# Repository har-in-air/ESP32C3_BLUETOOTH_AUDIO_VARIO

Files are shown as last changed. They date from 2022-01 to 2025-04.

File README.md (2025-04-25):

# ESP32C3_BLUETOOTH_AUDIO_VARIO

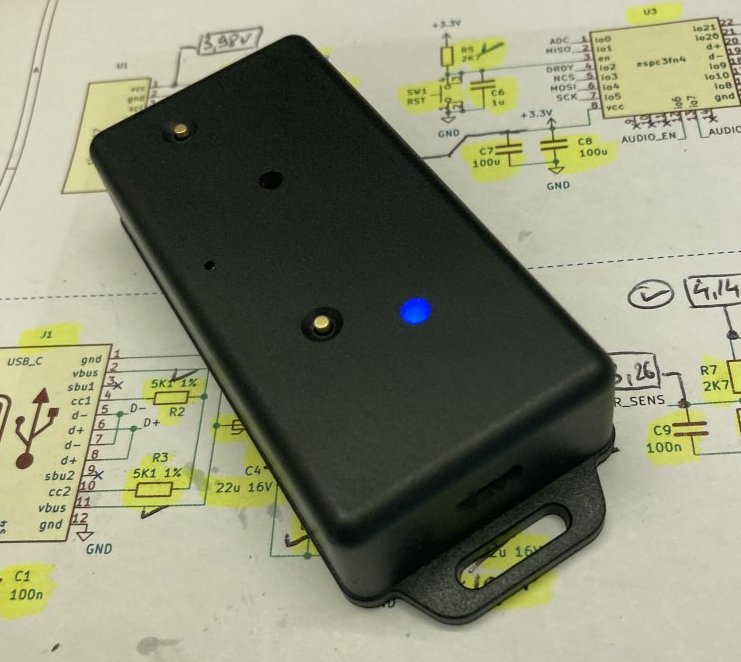
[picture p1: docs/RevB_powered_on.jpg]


 * Accurate, zero-lag audio variometer using Kalman filter fusion of accelerometer and pressure sensor data. 
 This project uses the [KF4D kalman filter algorithm](https://github.com/har-in-air/ESP32_IMU_BARO_GPS_VARIO/blob/master/offline/kf/compare_kf2_kf3_kf4.ipynb).

* WiFi Vario configuration via web page.
* Bluetooth LE transmission of [$LK8EX1 sentences](https://github.com/LK8000/LK8000/blob/master/Docs/LK8EX1.txt), to provide apps like [XCTrack](https://xctrack.org/) with 
accurate barometric pressure altitude and climb-rate data.
* Soft-switched power on/off.
* 'No activity' time-out power down  to conserve battery life.
* WiFi Over-the-air (OTA) firmware updates.
* [2-layer PCB layout available, sized for standard Hammond 1551K enclosure](https://github.com/har-in-air/VhARIO-ESPC3).

# Software Build Environment 
* Ubuntu 24.04 LTS AMDx64
* [Visual Studio Code with PlatformIO plugin using Arduino framework](https://randomnerdtutorials.com/vs-code-platformio-ide-esp32-esp8266-arduino/) 
* The file `platformio.ini` specifies the framework packages, toolchain and libraries used by the project. 
* LittleFS partition for hosting HTML web page content.
* Since release v1.20, the software only supports PCB layout revision B.

# Hardware

* AI-Thinker ESP-C3-12F C3FN4 module (4MByte flash, Wi-Fi and Bluetooth LE)
* CJMCU-117 module with MPU9250 9-DOF IMU and MS5611 barometric pressure sensor
* TLV75533 LDO regulator, max current 500mA
* KPEG006 broadband-audio piezo transducer
* 74HC240 used as a push-pull piezo driver for louder volume 
* MCP73871 Li-poly battery charger, max 500mA charging current
* 1800mAHr Lipoly battery
* The USB C interface supports Li-Poly battery charging and program flash/debug.

## Current Drain

With Bluetooth LE disabled, current drain is ~30mA.

With Bluetooth LE enabled and transmitting LK8EX1 messages at 10Hz, current drain is ~85mA.

# Software Build Notes

## Build Steps

* The first time you flash the ESP32-C3 with this project code, select `PROJECT TASKS -> esp32c3 -> Platform -> Erase Flash`. This will wipe the entire flash including any previous partition tables. 
* Next, select `Platform -> Build Filesystem Image`. This will build a LittleFS flash partition with the contents of the `/data` directory. The `/data` directory contains the static HTML and CSS files for the WiFi server webpage.
* Ensure the vario is switched off. 
* Connect the USB cable from your PC to the vario. 
* Press and hold the `PCCA (SW4)` button. 
* Close the jumper or slide-switch (`JP1/SW2)` depending on which part you have installed. 
* Release the `PCCA (SW4)` button. 
* You will see the USB serial/jtag port show up as a new serial port. On Ubuntu it will be `/dev/ttyACMx` instead of `/dev/ttyUSBx`. Set this new port as the upload and monitor port in platformio.ini.
* Next, select `Platform -> Upload Filesystem Image`. This will flash the LittleFS data partition to the ESP32-C3.
* Next, select `General -> Clean All`, then `Build`. This is only required once, to download the source code for the dependent libraries and build them. 
* If the libraries have already been downloaded and compiled, select `General -> Clean` to re-build only the project application code.
* Select `Build` to compile the application firmware binary. 
* Open the jumper/slide switch (`JP1/SW2`) to remove power. 
* Repeat the earlier steps with `PCCA (SW4)` and the jumper/slide switch  (`JP1/SW2`) to set up for flashing the application firmware.
* Select `Upload` to flash the application firmware binary.
* To see  serial debug prints and prompts on boot, open the  jumper/slide switch (`JP1/SW2`) to remove power. 
* Select `Monitor` in Visual Studio Code and then switch on the vario using the `PWR (SW3)` button. Note that the
serial port may change from the one used for upload e.g. from `ttyACM0` to `ttyACM1`.  

* After a full chip erase and firmware upload, there is no calibration data. So you will see a calibration error message. Follow the prompts to calibrate both accelerometer and gyroscope. Once complete, the calibration parameters will be saved to flash.
* [Example startup serial monitor output example after a full flash erase and build.](docs/first_boot_log.txt) 
* Example serial terminal output for normal vario boot (post-caliibration) : 

```
ESP-ROM:esp32c3-api1-20210207
Build:Feb  7 2021
ESP-ROM:esp32c3-api1-20210207
Build:Feb  7 2021
rst:0x15 (USB_UART_CHIP_RESET),boot:0xc (SPI_FAST_FLASH_BOOT)
Saved PC:0x42083766
SPIWP:0xee
mode:DIO, clock div:2
load:0x3fcd5810,len:0x438
load:0x403cc710,len:0x90c
load:0x403ce710,len:0x2624
entry 0x403cc710
E (236) esp_core_dump_flash: No core dump partition found!
E (236) esp_core_dump_flash: No core dump partition found!

ESP32-C3 BLUETOOTH VARIO compiled on Apr  8 2025 at 15:48:49
Firmware Revision 1.01

Load non-volatile configuration and calibration data from flash
WiFi AP credentials
SSID = 
VARIO
climbThresholdCps = 50
zeroThresholdCps = 5
sinkThresholdCps = -250
crossoverCps = 400
KALMAN FILTER
accelVariance = 100
adapt = 100
MISCELLANEOUS
pwrOffTimeoutMinutes = 10
bleEnable = true
Calibration Values
axBias = -390
ayBias = -182
azBias = 234
gxBias = 17
gyBias = -7
gzBias = 22
To start web configuration mode, press and hold the PCC button
until you hear a low-frequency tone. Then release the button
8
7
6
5
4
3
CPU Freq = 80 MHz
XTAL Freq = 40 MHz
APB Freq = 80000000 Hz
Vario mode

Audio indication of battery voltage

Battery voltage = 4.13V
E (4666) ledc: ledc_get_duty(745): LEDC is not initialized

Check communication with MS5611
crcPROM = 0x9, crc calculated = 0x9
MS5611 OK

Check communication with MPU9250
MPU9250 ID = 71, expected 0x71
MPU9250 OK
Counting down to gyro calibration
Press the PCCA button to enforce accelerometer calibration first
10
9
8
7
6
5
4
3
2
1

Calibrating gyro
Num Tries = 1
gxBias = 18
gyBias = -7
gzBias = 22
Gyro calibration OK

MS5611 config
MS5611 Calibration Coeffs : 48939 50595 29263 26380 30963 26826
Tavg : 35C
Pavg : 90986Pa
Zavg : 89864cm

KalmanFilter config
climbToneCps = 50
zeroesToneCps = 5
sinkToneCps = -250
crossoverCps = 400

Bluetooth LE LK8EX1 messages @ 10Hz

```
* The gyroscope is re-calibrated each time on power-up. You should leave the vario un-disturbed (in any orientation) when you hear the count-down beeps for gyroscope calibration. If the vario is disturbed during the gyro calibration process (e.g. you switched the vario on during flight), it will use the last saved gyro calibration parameters.

# WiFi Configuration

To put the vario into WiFi AP server mode, switch on the vario and immediately press and hold the `PCCA (SW4)` button. When you hear a confirmation tone, release the button. 

Connect to the WiFi Access Point `Vario-AP`, no password needed. 

Open the url `http://192.168.4.1` in a browser.
You can use `http://vario.local` with any OS that has mDNS support. MacOS has built-in support. For Ubuntu, install Avahi. For Windows, install Bonjour.

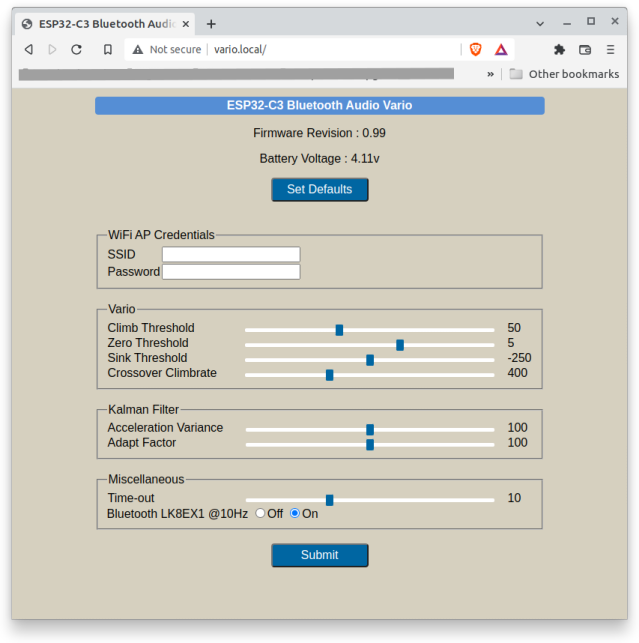
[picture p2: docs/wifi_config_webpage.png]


## Configuration Options

### WiFi Credentials
Enter your home WiFi Access Point SSID and password so that the vario can connect to the access point as a station. Then you can just enter the webpage url `http://vario.local` to access the vario configuration web page.

If the external Access Point is not configured or the configured access point is not available, e.g. on the launch site, the vario will configure itself as a standalone Wifi Access Point with SSID `Vario-AP`, no password. You can use your phone or tablet to connect first to this access point. Then access the webpage url `http://vario.local` as before.

### Audio Tone configuration

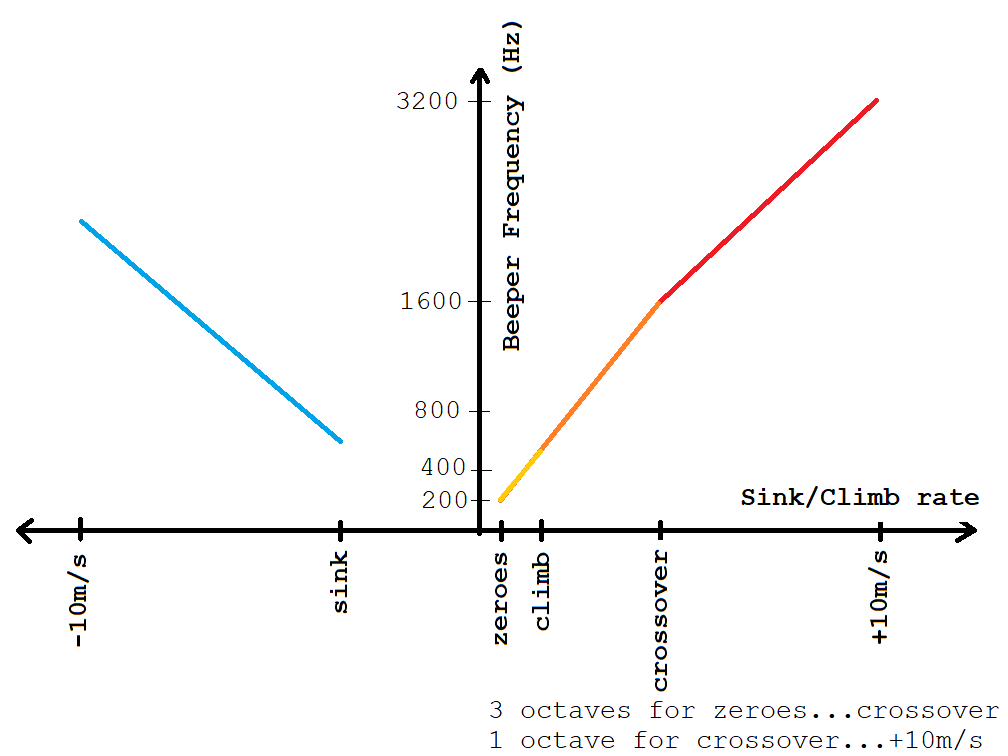
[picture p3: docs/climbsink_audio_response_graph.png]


The climb tone threshold should be configured for what you consider the minimum climbrate that you can turn in without losing height. The range is +20cm/s to +100cm/s.

Since a paraglider has a 'hands-up' sink rate of approximately -1m/s in still air, anything more than this indicates rising air. 
The zero tone is used to indicate air that is rising, but not strong enough for aggressive turns. The range is -20cm/s to +20cm/s. 

The sink tone is used to indicate sinking air, not a sinking glider. The range is -400cm/s to -100cm/s.

Note that these thresholds are purely personal choices, depending on how 'talkative' you want the vario to be.

The crossover climbrate is used to adjust the frequency discrimination. The vario allocates 3 octaves of audio bandwidth to climbrates below this threshold, and 1 octave
above the threshold. So if the expected average thermal strength is +5m/s, set the threshold to 500.

### Kalman Filter configuration
Set the `variance` parameter lower for conditions with soft, wide and smooth-edged thermals. Set the parameter higher for conditions with strong, narrow and hard-edged thermals.

The `adapt` parameter will probably be removed after flight trials. Higher values add more uncertainty into the Kalman filter so it can respond to high acceleration transitions quickly, while maintaining a high degree of damping in zero acceleration conditions.

### Inactivity Time-out
The vario will power off automatically to save battery life if it does not detect climb/sink rates beyond a minimum threshold within a specified interval (specified in minutes). If you often stand on the launch site for several minutes, hooked-up to the glider and waiting for launch conditions to improve, use a larger time-out.

### Bluetooth LK8EX1
If you enable this option, the vario will transmit $LK8EX1 sentences using the Bluetooth LE protocol at 10Hz. The Bluetooth device name is `BLE-Vario`.

`XCDisplay` app on Apple iPhone connected to the vario, displaying pressure altitude and climbrate.
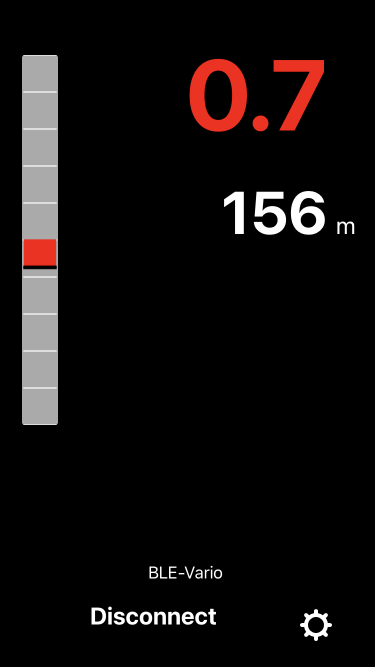
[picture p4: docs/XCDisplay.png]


# Usage

## Power On 
To power on, press the `PWR (SW3)` button and hold (~1 second) until you see the power/bluetooth LED turn on. Release.

The vario will first indicate the battery charge status with a series of long beeps. 5 beeps for fully charged, 1 beep for discharged.

After a pause, the vario will indicate the countdown to gyro calibration with a series of 10 shorter beeps. You should ensure the vario is left undisturbed, in any orientation (do not hold it in your hand). At the end of the countdown and a brief pause, you may hear an initial squawk as the filter initializes, but it should settle down in a few seconds. Now the vario is operational and providing audio feedback.

If you want to force accelerometer re-calibration, press the `PCCA (SW4)` button during the gyro calibration countdown. Now the vario will start a 50 short beep countdown at a fast rate. At this point you should place the vario flat on a horizontal surface (confirm with a bubble level if possible) without any disturbance, vibrations etc. Do not hold or press down on the vario case. At the end of the 50 beeps, the accelerometer will be calibrated, and then the countdown to gyro calibration will start.

### Power/Bluetooth LED
If Bluetooth transmission is disabled, the power/bluetooth LED will stay on.

If Bluetooth transmission is enabled, the power/bluetooth LED will start blinking once every 2 seconds after transmission starts.

### Audio Mute 
When the vario has finished initialization and is providing vario audio feedback, a brief press of the `PCCA (SW4)` button  will toggle the audio on / off.

This is convenient if you have set the zero-tone threshold to a negative value or close to zero and don't want the distraction of a beeping vario while you are hooked in to the glider and waiting to launch.

## Power Off
To power off, press the `PWR (SW3)` button and hold (~2 seconds) until you hear a confirmation audio tone. If the power/bluetooth LED was on, it will turn off as well. Release.

# Notes on Calibration and Use
The accelerometer offset calibration with the vario in a horizontal position needs to be done AFTER the board is installed in the case and BEFORE first use.

Gyro offset calibration is done on each power up. For that the only requirement is that the unit should not be disturbed, it can be in any orientation.  If it is disturbed, it will use the previous saved gyro offsets. This will not be an issue  if you successfully calibrated the gyro in the past few days and are flying in similar temperature conditions.

After offset calibration and in normal use the AHRS software computes the vario orientation in Earth coordinates and then the 
net acceleration along the Earth coordinates +Z axis, every 2mS. This is NOT the IMU chip z axis acceleration. 

So the vario does not have to be horizontal during use, you can mount it to your waist strap or riser.

You will need to redo the accelerometer offset calibration if you have reinstalled the board in the case, or tightened/loosened the mounting screws. The stress from the mounting screws will translate to stress on the MEMS structures in the IMU chip soldered to the module board, which will change the axis offsets. 

My friend who mounted the module board with a standard 0.1in header to the main PCB had very large accelerometer offsets. I was concerned that he had a defective MPU9250 chip. He reinstalled the IMU module board with double-sided foam tape and thin flexible wires, and then the offsets on all axes were very low.

The accelerometer calibration will remove the offsets, but it's good to remove external contributing factors, especially if the offset is so large that it affects the dynamic range. 

# Credits

Prototype design, component sourcing, PCB assembly and testing in collaboration with Benoit Arnal.

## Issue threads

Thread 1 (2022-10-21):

[Enhancement] Power off Vario if the battery level is too low.

olekuz, 2022-10-21:
It would be nice to showdown Vario when the battery level is critically low to prevent over-discharge and save the battery from degradation.

har-in-air, 2022-10-21:
Commercial Lipoly batteries  already have protection  modules for overcharge and overdischarge and max current. It's the thin rectangular  pcb connected to the raw battery tabs. You shouldn't  be using a raw lipoly or liion battery without the protection  module. You can find replacement  boards easily on aliexpress  etc. They are specified by the voltage 1S, 2S etc and the max  current.

Sent from Yahoo Mail on Android

  On Fri, 21 Oct 2022 at 14:27, Oleksandr ***@***.***> wrote:

It would be nice to showdown Vario when the battery level is critically low to prevent over-discharge and save the battery from degradation.

—
Reply to this email directly, view it on GitHub, or unsubscribe.
You are receiving this because you are subscribed to this thread.Message ID: ***@***.***>

Closed 2022-10-24.

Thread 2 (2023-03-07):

SPI Problem

Levardar, 2023-03-07:
Hello.

I am trying to run my new miniVario based on your nice project.
I have problems connecting to MS5611 and MPU9250(CJMCU-10DOF). As I start the device I have this errors:

`Audio indication of battery voltage

Battery voltage = 4.05V
E (5945) ledc: ledc_get_duty(739): LEDC is not initialized

Check communication with MS5611
crcPROM = 0xF, crc calculated = 0x0
Bad CRC read from MS5611 calibration PROM
MS5611 OK

Check communication with MPU9250
MPU9250 ID = 00, expected 0x71
Error reading Mpu9250 WHO_AM_I register
MPU9250 OK`

I commented out the powerOff() option to see what's happening after checking the connection with them, that's way continues to MS5611 OK and MPU9250 OK.
I think there is a problem with the SPI connection. I checked all the connection but everything looks fine.
I am using ESP32-C3-WROOM-02 with the same connection as you have in REV B
Platform.io is set up to use this version

`; HW REV B
build_flags =
	-DARDUINO_USB_MODE=1
	-DHW_REV_B
;	-DARDUINO_USB_CDC_ON_BOOT

; HW REV A
;build_flags =
;	-DHW_REV_A`

Maybe you could give me some advice to debug this problem when you have time.

Thank you,
Razvan

har-in-air, 2023-03-08:
Try comparing the schematic of the wroom module versus the c3fn4, also the imu sensor board schematic  if you used a different  one. Could try putting  10k pullup resistors on the cs lines for the ms5611 and mpu9250. Maybe  obvious  but check the power supply for the sensors

Sent from Yahoo Mail on Android

  On Wed, 8 Mar 2023 at 5:26, Razvan ***@***.***> wrote:

Hello.

I am trying to run my new miniVario based on your nice project.
I have problems connecting to MS5611 and MPU9250(CJMCU-10DOF). As I start the device I have this errors:

`Audio indication of battery voltage

Battery voltage = 4.05V
E (5945) ledc: ledc_get_duty(739): LEDC is not initialized

Check communication with MS5611
crcPROM = 0xF, crc calculated = 0x0
Bad CRC read from MS5611 calibration PROM
MS5611 OK

Check communication with MPU9250
MPU9250 ID = 00, expected 0x71
Error reading Mpu9250 WHO_AM_I register
MPU9250 OK`

I commented out the powerOff() option to see what's happening after checking the connection with them, that's way continues to MS5611 OK and MPU9250 OK.
I think there is a problem with the SPI connection. I checked all the connection but everything looks fine.
I am using ESP32-C3-WROOM-02 with the same connection as you have in REV B
Platform.io is set up to use this version

`; HW REV B
build_flags =
-DARDUINO_USB_MODE=1
-DHW_REV_B
; -DARDUINO_USB_CDC_ON_BOOT

; HW REV A
;build_flags =
; -DHW_REV_A`

Maybe you could give me some advice to debug this problem when you have time.

Thank you,
Razvan

—
Reply to this email directly, view it on GitHub, or unsubscribe.
You are receiving this because you are subscribed to this thread.Message ID: ***@***.***>

Levardar, 2023-03-10:
I tried with the pullups but without success and then I use a oscilloscope to test the CSB(without 10K pullups). On start is going HIGH but never goes LOW.

har-in-air, 2023-03-10:
Try printing  out what pinNCS and pinCSB are in spi_init()

Sent from Yahoo Mail on Android

  On Fri, 10 Mar 2023 at 12:31, Razvan ***@***.***> wrote:

I tried with the pullups but without success and then I use a oscilloscope to test the CSB(without 10K pullups). On start is going HIGH but never goes LOW.

—
Reply to this email directly, view it on GitHub, or unsubscribe.
You are receiving this because you commented.Message ID: ***@***.***>

Levardar, 2023-03-10:
Spi_init debug:
MS5611 CS pin status: 0
MPU CS pin status: 1

har-in-air, 2023-03-11:
I would first check the WROOM module schematic against the C3FN4 schematic for differences.
I haven't had trouble with a hand wired prototype, or with the assembled pcb, and it was independentlyassembled and tested in France by my partner on the project.
You could try setting the CS pins to output and drive to 1 in the code before calling spi_init()

    On Friday, 10 March, 2023 at 06:18:57 pm IST, Razvan Levarda ***@***.***> wrote:

Spi_init debug:
MS5611 CS pin status: 0
MPU CS pin status: 1

—
Reply to this email directly, view it on GitHub, or unsubscribe.
You are receiving this because you commented.Message ID: ***@***.***>

devenergize, 2023-03-12:
I found that the cjmcu-117 was the problem. I change it and now it's working. I'm just waiting to fly with it and test it. Thank you for your support and for the cool project you've done!

Levardar, 2023-03-12:
I found the problem, it was the cjmcu-117. I change it and now it's working. I am just waiting to fly with it and test it. Thank you for your support and for this cool project.

Closed 2023-03-12.

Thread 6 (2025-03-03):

Compile results in several 'USBSerial' was not declared in this scope

davinderc, 2025-03-03:
I'm trying to compile for the seeed_xiao_esp32c3 (I have an ESP32-C3 Super Mini) on a Mac using PlatformIO and I cannot seem to figure out why I get errors related to `USBSerial` not being declared in `config.h`. Below is my `platformio.ini` and aside from that everything else is as checked out from main. Some of the compiler errors are below.

https://github.com/har-in-air/ESP32C3_BLUETOOTH_AUDIO_VARIO/blob/552cd865ce0543e66bbb5320b5269188a9265681/src/config.h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

```[env:esp32c3]
platform = espressif32 @ 6.9.0
framework = arduino
board = seeed_xiao_esp32c3
board_build.flash_mode = qio
board_build.partitions = partitions.csv
board_build.filesystem = littlefs
board_build.f_cpu = 160000000L
board_build.f_flash = 80000000L
build_flags =
	-DARDUINO_USB_MODE=1
	-DHW_REV_B
lib_deps =
	h2zero/NimBLE-Arduino@^1.4.0
	AsyncElegantOTA
	AsyncTCP
	https://github.com/har-in-air/ESPAsyncWebServer.git
upload_speed = 921600
monitor_speed = 115200
build_type = debug
monitor_filters = esp32_exception_decoder
upload_port = /dev/cu.usbmodem1101
monitor_port = /dev/tty.usbmodem1101
```

```
Building in debug mode
Compiling .pio/build/esp32c3/src/adc.cpp.o
Compiling .pio/build/esp32c3/src/audio.cpp.o
Compiling .pio/build/esp32c3/src/ble_uart.cpp.o
Compiling .pio/build/esp32c3/src/imu.cpp.o
Compiling .pio/build/esp32c3/src/kalmanfilter4d.cpp.o
Compiling .pio/build/esp32c3/src/main.cpp.o
Compiling .pio/build/esp32c3/src/mpu9250.cpp.o
Compiling .pio/build/esp32c3/src/ms5611.cpp.o
Compiling .pio/build/esp32c3/src/nvd.cpp.o
Compiling .pio/build/esp32c3/src/ringbuf.cpp.o
In file included from src/mpu9250.cpp:2:
src/mpu9250.cpp: In member function 'int MPU9250::check_id()':
src/config.h:38:16: error: 'USBSerial' was not declared in this scope
 #define Serial USBSerial
                ^~~~~~~~~
src/config.h:152:26: note: in expansion of macro 'Serial'
  #define dbg_printf(x)  {Serial.printf x;}
                          ^~~~~~
src/mpu9250.cpp:33:2: note: in expansion of macro 'dbg_printf'
  dbg_printf(("MPU9250 ID = %02X, expected 0x71\n", id));
  ^~~~~~~~~~
src/config.h:38:16: note: suggested alternative: 'Serial'
 #define Serial USBSerial
                ^~~~~~~~~
src/config.h:152:26: note: in expansion of macro 'Serial'
  #define dbg_printf(x)  {Serial.printf x;}
                          ^~~~~~
src/mpu9250.cpp:33:2: note: in expansion of macro 'dbg_printf'
  dbg_printf(("MPU9250 ID = %02X, expected 0x71\n", id));
  ^~~~~~~~~~
src/mpu9250.cpp: In member function 'void MPU9250::get_calib_params(CALIB_PARAMS_t&)':
src/config.h:38:16: error: 'USBSerial' was not declared in this scope
 #define Serial USBSerial
                ^~~~~~~~~
src/config.h:151:26: note: in expansion of macro 'Serial'
  #define dbg_println(x) {Serial.println x;}
                          ^~~~~~
src/mpu9250.cpp:55:2: note: in expansion of macro 'dbg_println'
  dbg_println(("Calibration parameters from NVD"));
  ^~~~~~~~~~~
In file included from src/nvd.cpp:3:
src/nvd.cpp: In function 'void nvd_calib_load(CALIB_PARAMS_t&)':
src/config.h:38:16: error: 'USBSerial' was not declared in this scope
 #define Serial USBSerial
                ^~~~~~~~~
src/config.h:151:26: note: in expansion of macro 'Serial'
  #define dbg_println(x) {Serial.println x;}
                          ^~~~~~
src/nvd.cpp:17:3: note: in expansion of macro 'dbg_println'
   dbg_println(("Preferences 'calib' namespace not found, creating with defaults"));
   ^~~~~~~~~~~
src/config.h:38:16: note: suggested alternative: 'Serial'
 #define Serial USBSerial
                ^~~~~~~~~
src/config.h:151:26: note: in expansion of macro 'Serial'
  #define dbg_println(x) {Serial.println x;}
                          ^~~~~~
src/mpu9250.cpp:55:2: note: in expansion of macro 'dbg_println'
  dbg_println(("Calibration parameters from NVD"));
  ^~~~~~~~~~~
src/config.h:38:16: error: 'USBSerial' was not declared in this scope
 #define Serial USBSerial
                ^~~~~~~~~
src/config.h:152:26: note: in expansion of macro 'Serial'
  #define dbg_printf(x)  {Serial.printf x;}
                          ^~~~~~
src/mpu9250.cpp:56:2: note: in expansion of macro 'dbg_printf'
  dbg_printf(("axBias %d, ayBias %d, azBias %d\n",axBias, ayBias, azBias));
  ^~~~~~~~~~
In file included from src/ms5611.cpp:2:
src/ms5611.cpp: In member function 'void MS5611::averaged_sample(int)':
src/config.h:38:16: error: 'USBSerial' was not declared in this scope
 #define Serial USBSerial
                ^~~~~~~~~
src/config.h:152:26: note: in expansion of macro 'Serial'
  #define dbg_printf(x)  {Serial.printf x;}
                          ^~~~~~
src/ms5611.cpp:97:4: note: in expansion of macro 'dbg_printf'
    dbg_printf(("Tavg : %dC\r\n", temperatureC));
    ^~~~~~~~~~
src/config.h:38:16: note: suggested alternative: 'Serial'
 #define Serial USBSerial
                ^~~~~~~~~
src/config.h:151:26: note: in expansion of macro 'Serial'
  #define dbg_println(x) {Serial.println x;}
                          ^~~~~~
src/nvd.cpp:17:3: note: in expansion of macro 'dbg_println'
   dbg_println(("Preferences 'calib' namespace not found, creating with defaults"));
   ^~~~~~~~~~~
```

SPD13, 2025-03-28:
It worked for me by having the following libs in "lib_deps":
`	ESP32Async/AsyncTCP
	ElegantOTA
	ESP32Async/ESPAsyncWebServer`

har-in-air, 2025-04-05:
Try the latest check in and let me know if you see any issues

har-in-air, 2025-04-08:
Fixed and tested

Closed 2025-04-08.

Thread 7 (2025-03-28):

How to make it work with the accelerometer z axis not facing in the same direction during calibration and flight?

SPD13, 2025-03-28:
I would like to be able to start the device flat and then hand it to my riser. The orientation during flight will be different from the orientation during calibration as I would like to hand the device on my risers. What modification would you recommend?
Idea 1: Map the calibration process to a button to restart calibration after the device has been powered up. Cons: The paraglider needs to be up and the air and it would require to either let go of the brake of pull the brake toward the riser to press the button
Idea 2: if there is 1g on one axis for X seconds, then use this as the new calibration.
Do you know how "instant varios" are usually managing this problem? I don't see a systematic calibration at each boot up happening on the Flymaster for example.

har-in-air, 2025-03-28:
The accelerometer offset calibration with the vario horizontal only needs to be done once AFTER the board is installed in thecase and before first use.
Gyro offset calibration is done on each power up. For that the only requirement is that the unit should not be disturbed, it can be in any orientation.  If it is disturbed, it will use the previous saved gyro offsetswhich would not be an issue  if you successfully calibrated the gyro in the past few daysand are flying in similar temperature conditions.
After offset calibration the AHRS software uses the computed  Earth coordinates vario orientation to determine the Earth coordinates z axis net acceleration, this is NOT the IMU chip z axis acceleration. 
So the vario does not have to be flat during use, you can mount it to your waist strap or riser.

What can affect the offfset calibrations is if you have removed the board from the case and reinstalled it. The stress from the mounting screws will translate to stress on the MEMS structures in the IMUchip soldered to the board. So if you reinstall the board in the case you should redo the acceleration calibration.
The IMU module should be mounted with double sided foam tape and thin flexible wires to the pcb to mitigate this. . My friend who mounted the modulewith standard 0.1in header pins to the main pcb had some rather large offsets on the accelerometer. I was concerned that he had a defective chip and told himhow I had mounted my board. He reinstalled the module with thin flex wires and the foam tape and had even lower offsets than mine.
Of course the calibration will remove the offsets, but its good to remove external contributing factors.  This is why you see the pcb boards on drones mounted to the chassis with silicone dampers. 

I should make a note of this in the README
For a video demo of vario working in various orientations (post calibration of course) see Kalman Filter Sensor Fusion of Altitude and Acceleration Data 

|
|
|
|  |  |

 |

 |
|
|  |
Kalman Filter Sensor Fusion of Altitude and Acceleration Data

 |

 |

 |

    On Friday 28 March, 2025 at 06:12:07 am IST, Sebastien Bock ***@***.***> wrote:

I would like to be able to start the device flat and then hand it to my riser. The orientation during flight will be different from the orientation during calibration as I would like to hand the device on my risers. What modification would you recommend?
Idea 1: Map the calibration process to a button to restart calibration after the device has been powered up. Cons: The paraglider needs to be up and the air and it would require to either let go of the brake of pull the brake toward the riser to press the button
Idea 2: if there is 1g on one axis for X seconds, then use this as the new calibration.
Do you know how "instant varios" are usually managing this problem? I don't see a systematic calibration at each boot up happening on the Flymaster for example.

—
Reply to this email directly, view it on GitHub, or unsubscribe.
You are receiving this because you are subscribed to this thread.Message ID: ***@***.***>
SPD13 created an issue (har-in-air/ESP32C3_BLUETOOTH_AUDIO_VARIO#7)
I would like to be able to start the device flat and then hand it to my riser. The orientation during flight will be different from the orientation during calibration as I would like to hand the device on my risers. What modification would you recommend?
Idea 1: Map the calibration process to a button to restart calibration after the device has been powered up. Cons: The paraglider needs to be up and the air and it would require to either let go of the brake of pull the brake toward the riser to press the button
Idea 2: if there is 1g on one axis for X seconds, then use this as the new calibration.
Do you know how "instant varios" are usually managing this problem? I don't see a systematic calibration at each boot up happening on the Flymaster for example.

—
Reply to this email directly, view it on GitHub, or unsubscribe.
You are receiving this because you are subscribed to this thread.Message ID: ***@***.***>

SPD13, 2025-03-28:
Thank you so much for the detailed answer! More importantly thank you for this fantastic project!
I am working on a version that uses a cheap esp-32 with a built-in battery charger and I added an e-paper display and a second button, it's working fantastic! I have a clean climb graph and 2 resettable altitude (landing and launching). I tested and have more than 9h battery on a 18650 cell.
I will of course publish the code and documentation on github and give you proper credit.

har-in-air, 2025-03-28:
Thanks, let me know when you have published the code, I will backport the fixes for the compilation errors. 
regardsHari
    On Friday 28 March, 2025 at 08:01:04 am IST, Sebastien Bock ***@***.***> wrote:

Thank you so much for the detailed answer! More importantly thank you for this fantastic project!
I am working on a version that uses a cheap esp-32 with a built-in battery charger and I added an e-paper display and a second button, it's working fantastic! I have a clean climb graph and 2 resettable altitude (landing and launching). I tested and have more than 9h battery on a 18650 cell.
I will of course publish the code and documentation on github and give you proper credit.

—
Reply to this email directly, view it on GitHub, or unsubscribe.
You are receiving this because you commented.Message ID: ***@***.***>
SPD13 left a comment (har-in-air/ESP32C3_BLUETOOTH_AUDIO_VARIO#7)
Thank you so much for the detailed answer! More importantly thank you for this fantastic project!
I am working on a version that uses a cheap esp-32 with a built-in battery charger and I added an e-paper display and a second button, it's working fantastic! I have a clean climb graph and 2 resettable altitude (landing and launching). I tested and have more than 9h battery on a 18650 cell.
I will of course publish the code and documentation on github and give you proper credit.

—
Reply to this email directly, view it on GitHub, or unsubscribe.
You are receiving this because you commented.Message ID: ***@***.***>

Closed 2025-03-28.

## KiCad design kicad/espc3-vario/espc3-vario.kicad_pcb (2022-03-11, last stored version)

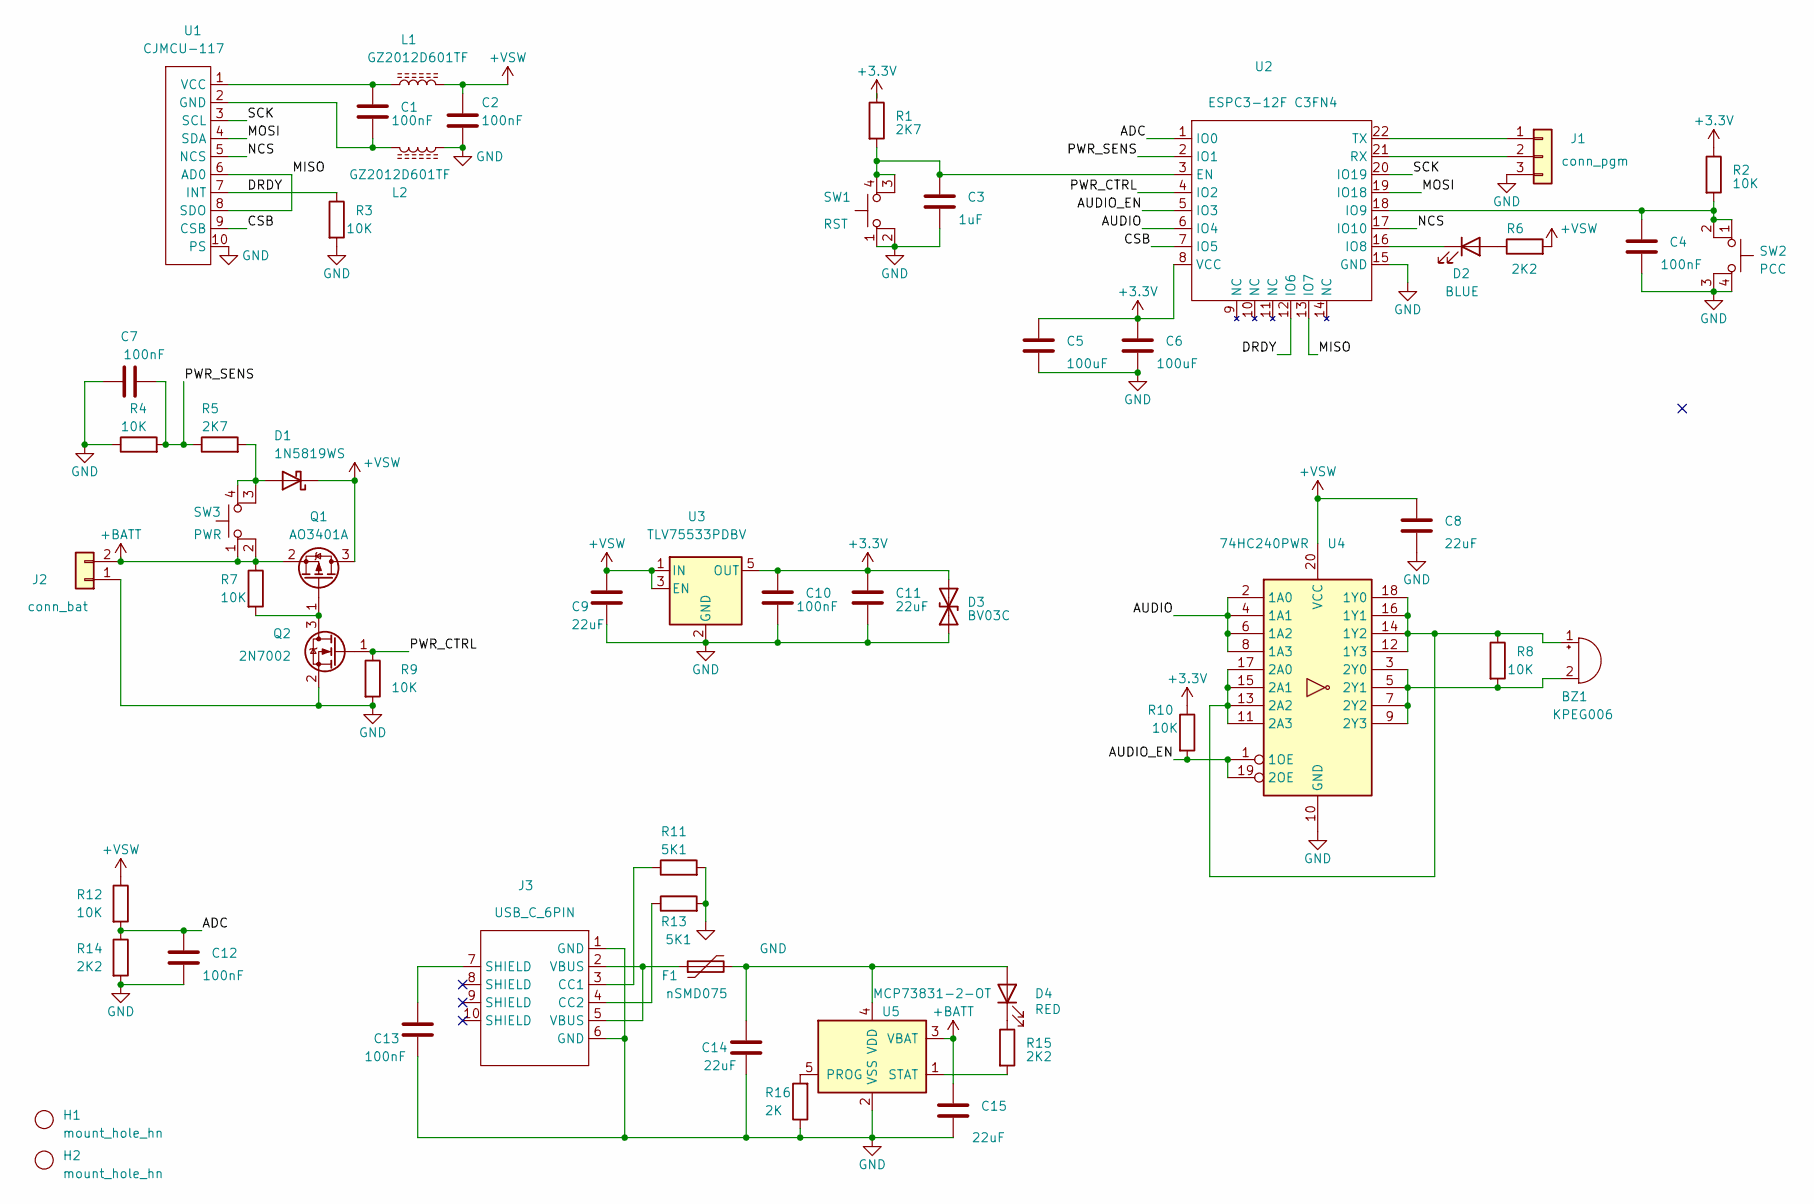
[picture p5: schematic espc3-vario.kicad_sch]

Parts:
BZ1: KPEG006; smd_conn2_hn
C1, C2, C4, C7, C10, C12, C13: 100nF; C_0805_2012Metric_Pad1.18x1.45mm_HandSolder
C3: 1uF; C_0805_2012Metric_Pad1.18x1.45mm_HandSolder
C5, C6: 100uF; C_1206_3216Metric_Pad1.33x1.80mm_HandSolder
C8, C9, C11, C14, C15: 22uF; C_1206_3216Metric_Pad1.33x1.80mm_HandSolder
D1: 1N5819WS; D_SOD-323_HandSoldering
D2: BLUE; LED_0805_2012Metric_Pad1.15x1.40mm_HandSolder
D3: BV03C; D_SOD-323_HandSoldering
D4: RED; LED_0805_2012Metric_Pad1.15x1.40mm_HandSolder
F1: nSMD075; Fuse_1206_3216Metric_Pad1.42x1.75mm_HandSolder
H1, H2: mount_hole_hn; MountingHole_2.5mm
J1: conn_pgm; pgm_conn_hn
J2: conn_bat; smd_conn2_hn
J3: USB_C_6PIN; usbc_6pin_hn
L1, L2: GZ2012D601TF; L_0805_2012Metric_Pad1.15x1.40mm_HandSolder
Q1: AO3401A; SOT-23_Handsoldering
Q2: 2N7002; SOT-23_Handsoldering
R1, R5: 2K7; R_0805_2012Metric_Pad1.20x1.40mm_HandSolder
R2, R3, R4, R7, R8, R9, R10, R12: 10K; R_0805_2012Metric_Pad1.20x1.40mm_HandSolder
R6, R14, R15: 2K2; R_0805_2012Metric_Pad1.20x1.40mm_HandSolder
R11, R13: 5K1; R_0805_2012Metric_Pad1.20x1.40mm_HandSolder
R16: 2K; R_0805_2012Metric_Pad1.20x1.40mm_HandSolder
SW1: RST; smd_btn4_hn
SW2: PCC; smd_btn4_hn
SW3: PWR; smd_btn4_hn
U1: CJMCU-117; cjmcu_117_hn
U2: ESPC3-12F C3FN4; espc3fn4_hn
U3: TLV75533PDBV; SOT-23-5_HandSoldering
U4: 74HC240PWR; SSOP-20_4.4x6.5mm_P0.65mm
U5: MCP73831-2-OT; SOT-23-5_HandSoldering

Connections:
+3V3: C5.1, C6.1, C10.1, C11.1, D3.2 (A2), R1.1, R2.1, R10.1, U2.8 (VCC), U3.5 (OUT)
+BATT: C15.1, J2.2, Q1.2 (S), R7.1, SW3.1, SW3.2, U5.3 (VBAT)
+VSW: C2.1, C8.1, C9.1, D1.1 (K), L1.2, Q1.3 (D), R6.2, R12.1, U3.1 (IN), U3.3 (EN), U4.20 (VCC)
/ADC: C12.1, R12.2, R14.1, U2.1 (IO0)
/AUDIO: U2.6 (IO4), U4.2 (1A0), U4.4 (1A1), U4.6 (1A2), U4.8 (1A3)
/AUDIO_EN: R10.2, U2.5 (IO3), U4.1 (1OE), U4.19 (2OE)
/CSB: U1.9 (CSB), U2.7 (IO5)
/DRDY: R3.1, U1.7 (INT), U2.12 (IO6)
/MISO: U1.6 (AD0), U1.8 (SDO), U2.13 (IO7)
/MOSI: U1.4 (SDA), U2.19 (IO18)
/NCS: U1.5 (NCS), U2.17 (IO10)
/PWR_CTRL: Q2.1 (G), R9.1, U2.4 (IO2)
/PWR_SENS: C7.2, R4.2, R5.1, U2.2 (IO1)
/SCK: U1.3 (SCL), U2.20 (IO19)
GND: C2.2, C3.2, C4.2, C5.2, C6.2, C7.1, C8.2, C9.2, C10.2, C11.2, C12.2, C13.2, C14.2, C15.2, D3.1 (A1), J1.3, J2.1, J3.1 (GND), J3.6 (GND), L2.1, Q2.2 (S), R3.2, R4.1, R9.2, R11.2, R13.2, R14.2, R16.1, SW1.1, SW1.2, SW2.3 (K), SW2.4 (A), U1.10 (PS), U2.15 (GND), U3.2 (GND), U4.10 (GND), U5.2 (VSS)
unnamed: BZ1.2 (+), R8.2, U4.3 (2Y0), U4.5 (2Y1), U4.7 (2Y2), U4.9 (2Y3)
unnamed: BZ1.1 (-), R8.1, U4.11 (2A3), U4.12 (1Y3), U4.13 (2A2), U4.14 (1Y2), U4.15 (2A1), U4.16 (1Y1), U4.17 (2A0), U4.18 (1Y0)
unnamed: D1.2 (A), R5.2, SW3.3 (K), SW3.4 (A)
unnamed: D2.2 (A), R6.1
unnamed: D2.1 (K), U2.16 (IO8)
unnamed: C14.1, D4.2 (A), F1.2, U5.4 (VDD)
unnamed: D4.1 (K), R15.1
unnamed: J1.1, U2.22 (TX)
unnamed: J1.2, U2.21 (RX)
unnamed: J3.3 (CC1), R11.1
unnamed: J3.4 (CC2), R13.1
unnamed: C13.1, J3.7 (SHIELD)
unnamed: F1.1, J3.2 (VBUS), J3.5 (VBUS)
unnamed: Q1.1 (G), Q2.3 (D), R7.2
unnamed: C3.1, R1.2, SW1.3 (K), SW1.4 (A), U2.3 (EN)
unnamed: C1.2, L2.2, U1.2 (GND)
unnamed: C1.1, L1.1, U1.1 (VCC)
unnamed: C4.1, R2.2, SW2.1, SW2.2, U2.18 (IO9)
unnamed: R16.2, U5.5 (PROG)
unnamed: R15.2, U5.1 (STAT)

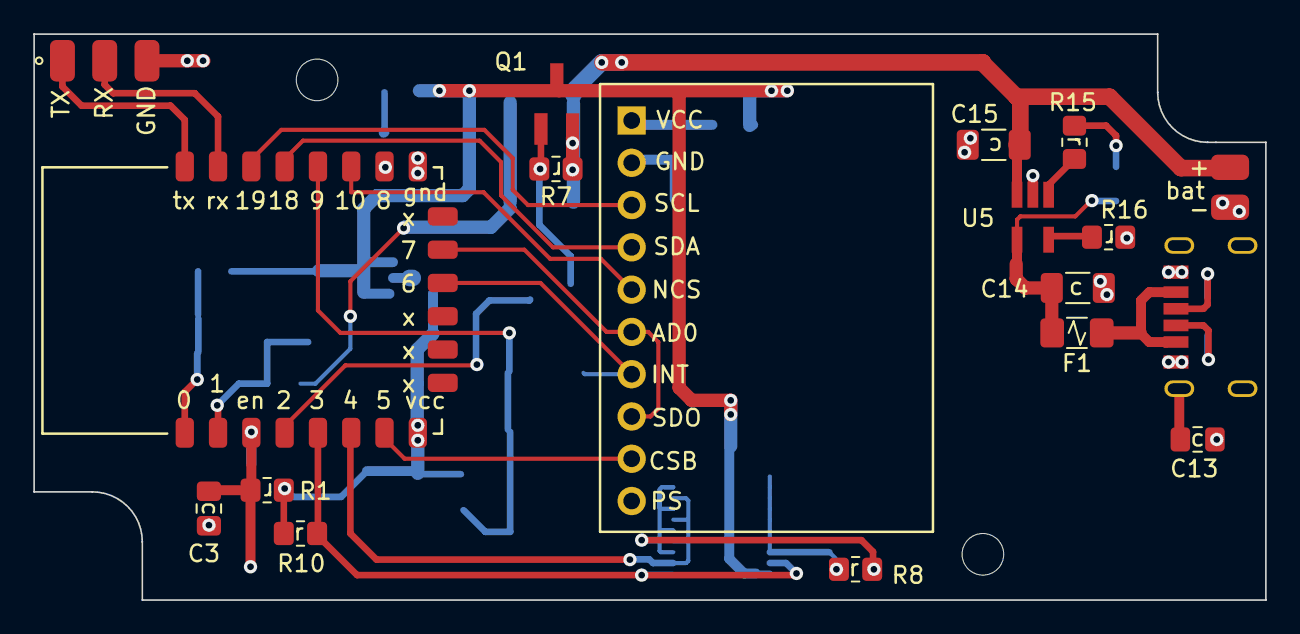
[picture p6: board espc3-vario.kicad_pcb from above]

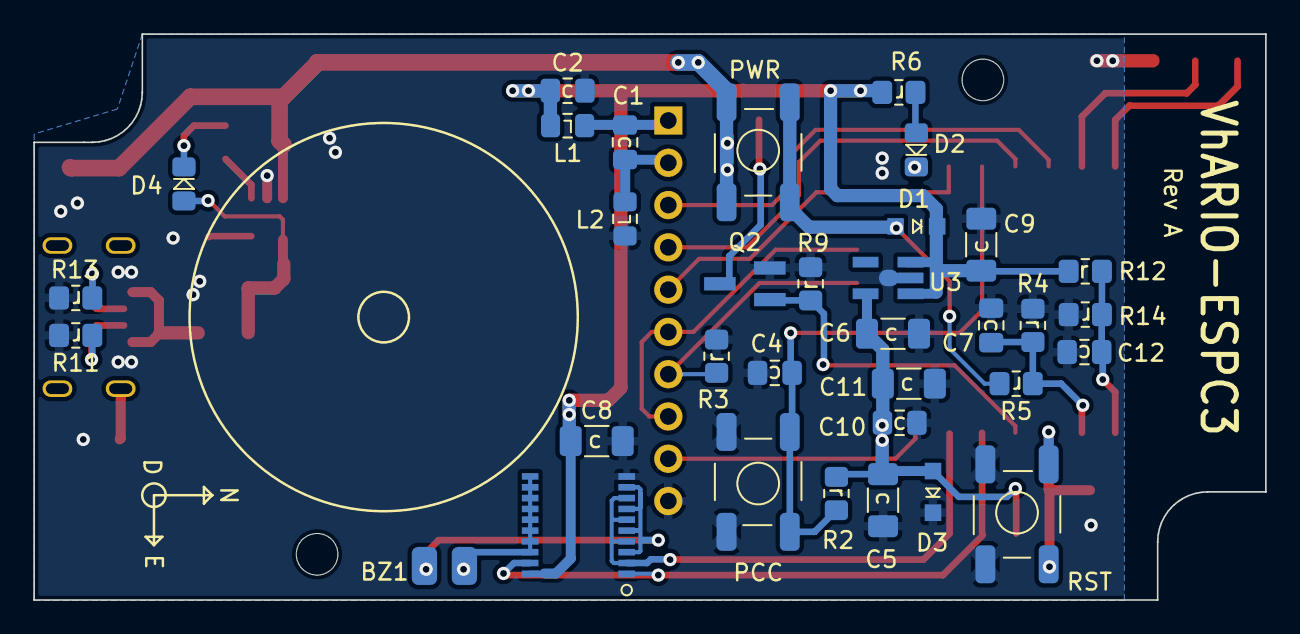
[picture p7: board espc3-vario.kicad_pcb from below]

Board: 2 copper layers, 74.0 x 34.0 mm, 54 parts (34 on the bottom side), 35 nets.

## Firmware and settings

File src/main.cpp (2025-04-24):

#include <Arduino.h>
#include <Wire.h>
#include <FS.h>
#include <LittleFS.h>
#include <ElegantOTA.h>
#include "config.h"
#include "spi.h"
#include "util.h"
#include "imu.h"
#include "mpu9250.h"
#include "ms5611.h"
#include "kalmanfilter4d.h"
#include "audio.h"
#include "vaudio.h"
#include "adc.h"
#include "nvd.h"
#include "ringbuf.h"
#include "wifi_cfg.h"
#include "ui.h"
#include "ble_uart.h"

const char* FwRevision = "1.10";

MPU9250	Imu;
MS5611	Baro;

boolean	bWebConfigure = false;

volatile SemaphoreHandle_t DrdySemaphore;
volatile int AltitudeM;
volatile int ClimbrateCps;
int LEDState;

static void drdy_interrupt_handler();
static void vario_task(void * pvParameter);
static void wifi_config_task(void * pvParameter);
static void pwr_ctrl_task(void* pvParameter);
static void ble_task(void* pvParameter);
static void power_off();

// PCCA button (GPIO9) has an external 10K pullup resistor to VCC
// This button has  different functions : program, configure, calibrate & audio toggle 
// 1. Program
//    Power on the unit with PCCA button pressed. Or with power on, keep 
//    PCCA pressed and momentarily press the reset button.
//    This will put the ESP32-C3 into programming mode, and you can flash 
//    the application code.
// 2. WiFi Configuration
//    After normal power on, immediately press PCCA and keep it pressed. 
//    Wait until you hear a low tone, then release. The unit will now be in WiFi configuration
//    configuration mode. 
// 3. Calibrate Accelerometer
//    After normal power on, wait until you hear the battery voltage feedback beeps and
//    then the countdown to gyroscope calibration. If you press the PCCA button
//    during the gyro calibration countdown, the unit will start accelerometer calibration first. 
//    Accelerometer re-calibration is required if the acceleration calibration values in 
//    flash were never written, or if the entire flash has been erased.
// 4. Audio Mute/Unmute  
//    When the vario is in normal operation, pressing PCCA will toggle the
//    vario audio feedback.


// handles data ready interrupt from MPU9250 (every 2ms)
static void IRAM_ATTR drdy_interrupt_handler() {
	BaseType_t xHigherPriorityTaskWoken = pdFALSE;
	xSemaphoreGiveFromISR(DrdySemaphore, &xHigherPriorityTaskWoken);
    if( xHigherPriorityTaskWoken == pdTRUE) {
        portYIELD_FROM_ISR(); // this wakes up vario_task immediately instead of on next FreeRTOS tick
		}	
	}	


void setup() {
	pinMode(pinPCCA, INPUT_PULLUP); //  Program/Configure/Calibrate/Audio Mute Button
	pinMode(pinPwrCtrl, OUTPUT); // soft-switch power on/off
	digitalWrite(pinPwrCtrl, LOW);
	pinMode(pinPwrSens, INPUT); // to detect  power-off button press

	pinMode(pinLED, OUTPUT_OPEN_DRAIN); // power/bluetooth LED, active low
	LED_OFF();
	pinMode(pinAudioEn, OUTPUT_OPEN_DRAIN); // output enable for 74HC240, active low
	digitalWrite(pinAudioEn, HIGH);

	wifi_off(); // turn off radio to save power

#ifdef TOP_DEBUG   
	// Serial print redirected to USB CDC port (on Ubuntu, shows up as /dev/ttyACMx)
	Serial.begin();
#endif

	// PWR button needs to be pressed for one second to switch on
	delay(1000);
	digitalWrite(pinPwrCtrl, HIGH);
	LED_ON();
	digitalWrite(pinAudioEn, LOW);
	spi_init();

	dbg_printf(("\n\nESP32-C3 BLUETOOTH VARIO compiled on %s at %s\n", __DATE__, __TIME__));
	dbg_printf(("Firmware Revision %s\n", FwRevision));

	dbg_println(("\nLoad non-volatile configuration and calibration data from flash"));  
	nvd_config_load(Config);
	nvd_calib_load(Calib);
	adc_init();
	int adcVal = adc_sample_average();
	BatteryVoltage = adc_battery_voltage(adcVal);

	bWebConfigure = false;
	dbg_println(("To start web configuration mode, press and hold the PCC button"));
	dbg_println(("until you hear a low-frequency tone. Then release the button"));
	for (int cnt = 0; cnt < 6; cnt++) {
		dbg_println((8-cnt));
		delay(500);
		if (digitalRead(pinPCCA) == 0) {
			bWebConfigure = true;
			break;
			}
		}

	setCpuFrequencyMhz(80);
	uint32_t Freq = getCpuFrequencyMhz();
	Serial.print("CPU Freq = ");
	Serial.print(Freq);
	Serial.println(" MHz");
	Freq = getXtalFrequencyMhz();
	Serial.print("XTAL Freq = ");
	Serial.print(Freq);
	Serial.println(" MHz");
	Freq = getApbFrequency();
	Serial.print("APB Freq = ");
	Serial.print(Freq);
	Serial.println(" Hz");		
   	
	xTaskCreate( pwr_ctrl_task, "pwr_ctrl_task", 1024, NULL, PWR_CTRL_TASK_PRIORITY, NULL );
	if (bWebConfigure == true) {
		dbg_println(("Web configuration mode"));
		// 3 second long tone with low frequency to indicate unit is now in web server configuration mode.
		// After you are done with web configuration, switch off the vario as the wifi radio
		// consumes a lot of power.
		audio_generate_tone(200, 3000);
    	xTaskCreate( wifi_config_task, "wifi_config_task", 4096, NULL, WIFI_CFG_TASK_PRIORITY, NULL );
		}
  	else {
		dbg_println(("Vario mode"));
		dbg_println(("\nAudio indication of battery voltage"));
		ui_indicate_battery_voltage(BatteryVoltage);
    	xTaskCreate( vario_task, "vario_task", 4096, NULL, VARIO_TASK_PRIORITY, NULL );
		}
	// delete the loopTask which called setup() from arduino app_main()
	vTaskDelete(NULL);
	}


static void power_off() {
	digitalWrite(pinPwrCtrl, LOW);
	LED_OFF();
	audio_generate_tone(200, 1000); // when you hear the tone, you can release the power button.
	audio_off();
	esp_deep_sleep_start(); // required as button is still pressed
	}


static void ble_task(void* pvParameter){
	ble_uart_init();
	int counter = 0;
	dbg_println(("\nBluetooth LE LK8EX1 messages @ 10Hz\n"));
	while (1) {
		counter++;
		if (counter > 9) {
			counter = 0;
			LEDState = !LEDState;
			digitalWrite(pinLED, LEDState);
			}
		BatteryVoltage = adc_battery_voltage();
		ble_uart_transmit_LK8EX1(AltitudeM, ClimbrateCps, BatteryVoltage);				
		vTaskDelay(100/portTICK_PERIOD_MS);
		}
	}


static void pwr_ctrl_task(void* pvParameter){
	int state = 0;
	int counter = 0;
	int timeoutCounter = (int)(PWR_OFF_DELAY_MS/(10UL*portTICK_PERIOD_MS));

	while (1) {
		switch (state) {
			case 0 :
			default :  
					if (digitalRead(pinPwrSens) == HIGH){
						counter = 0;
						state = 1;
						}
			break;
				
			case 1 : 
					if (digitalRead(pinPwrSens) == HIGH){
						counter++;
						if (counter >= timeoutCounter) {
							dbg_println(("Switching off power!"));
							power_off();
							}
						}
					else {
						state = 0;
						counter = 0;
						}
			break;
				}
		vTaskDelay(10 / portTICK_PERIOD_MS);
		}
	}


static void wifi_config_task(void * pvParameter) {
	if (!LittleFS.begin()){
		dbg_println(("Error mounting LittleFS, restarting..."));
		delay(1000);
		ESP.restart();
		}   
	wificfg_ap_server_init(); 
	while (1) {
		ElegantOTA.loop();
		// nothing to do, async web server 
		vTaskDelay(1);
		}
	vTaskDelete(NULL);
	}


static void vario_task(void * pvParameter) {
	float accelmG[3];  // milli-Gs
	float gyroDps[3];  // degrees/second
	float mag[3];      // unitless vector  
	float kfAltitudeCm = 0.0f; // kalman filtered altitude in cm
	float kfClimbrateCps = 0.0f;  // kalman filtered climb/sink rate in cm/s

	uint32_t timePreviousUs, timeNowUs; // time markers
	float imuTimeDeltaUSecs; // time between imu samples, in microseconds
	float kfTimeDeltaUSecs; // time between kalman filter updates, in microseconds

	int pwrOffCounter, baroCounter, drdyCounter;
	int pwrOffTimeoutSecs;

	dbg_println(("\nCheck communication with MS5611"));
	if (!Baro.read_prom()) {
		dbg_println(("Bad CRC read from MS5611 calibration PROM"));
		dbg_flush();
		ui_indicate_fault_MS5611(); 
		power_off();
		}
	dbg_println(("MS5611 OK"));
  
	dbg_println(("\nCheck communication with MPU9250"));
	if (!Imu.check_id()) {
		dbg_println(("Error reading Mpu9250 WHO_AM_I register"));
		dbg_flush();
		ui_indicate_fault_MPU9250();
		power_off();
		}
	dbg_println(("MPU9250 OK"));

#ifdef USE_9DOF_AHRS    
	// configure MPU9250 to start generating gyro, accel and mag data  
	Imu.config_accel_gyro_mag();
	// calibrate gyro (accel + mag if required)
	ui_calibrate_accel_gyro_mag();
#else
	// configure MPU9250 to start generating gyro, accel data  
	Imu.config_accel_gyro();
	// calibrate gyro (accel  if required)
	ui_calibrate_accel_gyro();
#endif
	delay(50);  
	  
	dbg_println(("\nMS5611 config"));
	Baro.reset();
	Baro.get_calib_coefficients(); // load MS5611 factory programmed calibration data
	Baro.averaged_sample(4); // get an estimate of starting altitude
	Baro.init_sample_state_machine(); // start the pressure & temperature sampling cycle

	dbg_println(("\nKalmanFilter config"));
	// initialize kalman filter with MS5611 estimated altitude, estimated initial climbrate = 0.0
	kalmanFilter4d_configure(1000.0f*(float)Config.kf.accelVariance, ((float)Config.kf.adapt)/100.0f, Baro.altitudeCmAvg, 0.0f, 0.0f);

	if (Config.misc.bleEnable) {
		xTaskCreate(ble_task, "ble_task", 4096, NULL, BLE_TASK_PRIORITY, NULL );
		}

	vaudio_config();  
	timeNowUs = timePreviousUs = micros();
	ringbuf_init(); 
	ui_btn_init();	
	// interrupt output of MPU9250 is configured as push-pull, active high pulse. This is connected to
	// pinDRDYInt which has an external 10K pull-down resistor
	pinMode(pinDRDYInt, INPUT); 
    DrdySemaphore = xSemaphoreCreateBinary();
	baroCounter = pwrOffCounter = drdyCounter = 0;
	pwrOffTimeoutSecs = 0;
	kfTimeDeltaUSecs = imuTimeDeltaUSecs = 0.0f;
	attachInterrupt(pinDRDYInt, drdy_interrupt_handler, RISING);

	while (1) {
		// MPU9250 500Hz ODR => 2mS sample interval
		// wait for data ready interrupt from MPU9250 
		xSemaphoreTake(DrdySemaphore, portMAX_DELAY); 
		timeNowUs = micros();
		imuTimeDeltaUSecs = timeNowUs > timePreviousUs ? (float)(timeNowUs - timePreviousUs) : 2000.0f; // if rollover use expected time difference
		timePreviousUs = timeNowUs;
		drdyCounter++;
		uint32_t marker = micros(); // set marker for estimating the time taken to read and process the data
#ifdef USE_9DOF_AHRS
		// accelerometer samples (ax,ay,az) in milli-Gs, gyroscope samples (gx,gy,gz) in degrees/second, mag samples are unitless
		Imu.get_accel_gyro_mag_data(accelmG, gyroDps, mag); 
#else
		// accelerometer samples (ax,ay,az) in milli-Gs, gyroscope samples (gx,gy,gz) in degrees/second
		Imu.get_accel_gyro_data(accelmG, gyroDps); 
#endif
		// For the CJMCU-117 IMU board orientation on the VhARIO-ESPC3 PCB layout,
		// we arbitrarily decide that the CJMCU-117 board silkscreen -X points "forward" or "north", 
		// silkscreen -Y points "right" or "east", and silkscreen +Z points down. This is our North-East-Down (NED) 
		// right-handed coordinate frame used in the AHRS algorithm implementation.
		// Then the mapping from IMU sensor frame to NED frame is : 
		// gn = gx, ge = -gy, gd = gz  : clockwise rotations about the + ned axis must result in +ve readings
		// an = ax, ae = ay, ad = -az   : when the + ned axis points down, axis reading must be +ve max
		// mn = -my, me = -mx, md = -mz   : when the + ned axis points magnetic north, axis reading must be +ve max
		// The AHRS algorithm expects rotation rates in radians/second
		// Acceleration data is only used for orientation correction when the acceleration magnitude is between 0.75G and 1.25G
		float accelMagnitudeSquared = accelmG[0]*accelmG[0] + accelmG[1]*accelmG[1] + accelmG[2]*accelmG[2];
		int bUseAccel = ((accelMagnitudeSquared > 562500.0f) && (accelMagnitudeSquared < 1562500.0f)) ? 1 : 0;
		float dtIMU = imuTimeDeltaUSecs/1000000.0f;

		float gn = DEG_TO_RAD*gyroDps[0];
		float ge = -DEG_TO_RAD*gyroDps[1];
		float gd = DEG_TO_RAD*gyroDps[2];
		float an = accelmG[0];
		float ae = accelmG[1];
		float ad = -accelmG[2];
#ifdef USE_9DOF_AHRS		
		float mn = -mag[1];
		float me = -mag[0];
		float md = -mag[2];
		imu_mahonyAHRS_update9DOF(bUseAccel, true, dtIMU, gn, ge, gd, an, ae, ad, mn, me, md);
#else
		imu_mahonyAHRS_update6DOF(bUseAccel, dtIMU, gn, ge, gd, an, ae, ad);
#endif		
		float gCompensatedAccel = imu_gravity_compensated_accel(an, ae, ad, Q0, Q1, Q2, Q3);
		ringbuf_add_sample(gCompensatedAccel);  
		baroCounter++;
		kfTimeDeltaUSecs += imuTimeDeltaUSecs;
		if (baroCounter >= 5) { // 5*2mS = 10mS elapsed, this is the sampling period for MS5611, 
			baroCounter = 0;    // alternating between pressure and temperature samples
			// one altitude sample is calculated for every new pair of pressure & temperature samples
			int zMeasurementAvailable = Baro.sample_state_machine(); 
			if ( zMeasurementAvailable ) { 
				// average earth-z acceleration over the 20mS interval between z samples
				// is used in the kf algorithm update phase
				float zAccelAverage = ringbuf_average_newest_samples(10); 
				float dtKF = kfTimeDeltaUSecs/1000000.0f;
				kalmanFilter4d_predict(dtKF);
				kalmanFilter4d_update(Baro.altitudeCm, zAccelAverage, (float*)&kfAltitudeCm, (float*)&kfClimbrateCps);
				// reset time elapsed between kalman filter algorithm updates
				kfTimeDeltaUSecs = 0.0f;
				AltitudeM = F_TO_I(kfAltitudeCm/100.0f);
				ClimbrateCps = F_TO_I(kfClimbrateCps);
				vaudio_tick_handler(ClimbrateCps); // audio feedback handler
				if (ABS(ClimbrateCps) > PWR_OFF_THRESHOLD_CPS) { 
					// reset power-off timeout watchdog if there is significant vertical motion
					pwrOffTimeoutSecs = 0;
					}
				else
				if (pwrOffTimeoutSecs >= (Config.misc.pwrOffTimeoutMinutes*60)) {
					dbg_println(("Timed out with no significant climb/sink, power down"));
					ui_indicate_power_off();
					power_off(); 
					}   
				}
			}
			
		if (BtnPCCAPressed) {
			BtnPCCAPressed = false;
			IsMuted = !IsMuted;
			if (IsMuted) audio_off();
			}	
		uint32_t elapsedUs =  micros() - marker; // calculate time  taken to read and process the data, must be less than 2mS
		if (drdyCounter >= 500) {
			drdyCounter = 0; // 1 second elapsed
			pwrOffTimeoutSecs++;
			#ifdef IMU_DEBUG
			//float yaw, pitch, roll;
			//imu_quaternion_to_yaw_pitch_roll(Q0,Q1,Q2,Q3, &yaw, &pitch, &roll);
			// Pitch is positive for clockwise rotation about the NED frame +Y axis
			// Roll is positive for clockwise rotation about the NED frame +X axis
			// Yaw is positive for clockwise rotation about the NED frame +Z axis
			// If magnetometer isn't used, yaw is initialized to 0 on power up.
			//dbg_printf(("\nY = %d P = %d R = %d\n", (int)yaw, (int)pitch, (int)roll));
			//dbg_printf(("kv = %d, timeout_counter = %d\n", (int)kfClimbrateCps, pwrOffTimeoutSecs));
			//dbg_printf(("ax = %.1f ay = %.1f az = %.1f\n",accelmG[0], accelmG[1], accelmG[2]));
			//dbg_printf(("gx = %.1f gy = %.1f gz = %.1f\n",gyroDps[0], gyroDps[1], gyroDps[2]));
			//dbg_printf(("mx = %.1f my = %.1f mz = %.1f\n",mag[0], mag[1], mag[2]));
			//dbg_printf(("Elapsed %dus\n", (int)elapsedUs)); 
			#endif     
			}
		}
	vTaskDelete(NULL);
	}


void loop(){
	}

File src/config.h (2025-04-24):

#ifndef CONFIG_H_
#define CONFIG_H_


#define pinPCCA		9	// program/configure/calibrate/audio button
#define pinAudio	7	// pwm beeper audio output
#define pinAudioEn	6	// 74HC240 output enables, active low

#define pinPwrSens	21	// detect power on/off button press
#define pinPwrCtrl	10	// power on/off

#define pinCSB		20	// CSB (ms5611)
#define pinMISO		1	// SDO ms5611 & AD0 mpu9250
#define pinNCS		3 	// NCS (mpu9250)
#define pinMOSI		4 	// SDA
#define pinSCK		5	// SCL
#define pinDRDYInt	2  	// INT
#define pinLED		8	// power-on and bluetooth active indication


#define BTN_PCCA()  (digitalRead(pinPCCA) == HIGH ? 1 : 0)

#define LED_ON() 	{digitalWrite(pinLED, 0); LEDState = 1;}
#define LED_OFF() 	{digitalWrite(pinLED, 1); LEDState = 0;}

#define PWR_ON_DELAY_MS		1000UL
#define PWR_OFF_DELAY_MS	2000UL

////////////////////////////////////////////////////////////////////
// WEB CONFIGURATION PARAMETER DEFAULTS AND LIMITS

// vario thresholds in cm/sec for generating different
// audio tones. Between the sink threshold and the zero threshold,
// the vario is quiet

#define VARIO_CLIMB_THRESHOLD_CPS_DEFAULT  	50
#define VARIO_CLIMB_THRESHOLD_CPS_MIN   	20
#define VARIO_CLIMB_THRESHOLD_CPS_MAX   	100

#define VARIO_ZERO_THRESHOLD_CPS_DEFAULT  	5
#define VARIO_ZERO_THRESHOLD_CPS_MIN    	-20
#define VARIO_ZERO_THRESHOLD_CPS_MAX    	20

#define VARIO_SINK_THRESHOLD_CPS_DEFAULT  	-250
#define VARIO_SINK_THRESHOLD_CPS_MIN    	-400
#define VARIO_SINK_THRESHOLD_CPS_MAX    	-100

// When generating climbtones, the vario allocates most of the speaker 
// frequency bandwidth to climbrates below this crossover threshold 
// so you have more frequency discrimination. So set the crossover threshold 
// to the average thermal core climbrate you expect for the site and conditions.
#define VARIO_CROSSOVER_CPS_DEFAULT     400
#define VARIO_CROSSOVER_CPS_MIN         300
#define VARIO_CROSSOVER_CPS_MAX         600

// Kalman filter configuration
#define KF_ACCEL_VARIANCE_DEFAULT     100
#define KF_ACCEL_VARIANCE_MIN         50
#define KF_ACCEL_VARIANCE_MAX         150

#define KF_ADAPT_DEFAULT	100
#define KF_ADAPT_MIN		50
#define KF_ADAPT_MAX		150

// Power-off timeout. The vario will power down
// if it does not detect climb or sink rates more than
// PWR_OFF_THRESHOLD_CPS, for the specified minutes.
#define PWR_OFF_TIMEOUT_MINUTES_DEFAULT   10
#define PWR_OFF_TIMEOUT_MINUTES_MIN       5
#define PWR_OFF_TIMEOUT_MINUTES_MAX       20

// audio feedback tones
#define BATTERY_TONE_HZ			400
#define CALIBRATING_TONE_HZ		800
#define UNCALIBRATED_TONE_HZ	2000
#define MPU9250_ERROR_TONE_HZ	200 
#define MS5611_ERROR_TONE_HZ	2500

// BLE LK8EX1 transmission is enabled as default
#define BLE_DEFAULT  true

////////////////////////////////////////////////////////////////////////////////
// COMPILED CONFIGURATION PARAMETERS ( cannot be changed with web configuration )

//#define USE_9DOF_AHRS

#define PWR_CTRL_TASK_PRIORITY	2
#define BLE_TASK_PRIORITY		3
#define WIFI_CFG_TASK_PRIORITY	3
#define VARIO_TASK_PRIORITY		(configMAX_PRIORITIES-2)

// change these parameters based on the frequency bandwidth of the speaker
#define VARIO_SPKR_MIN_FREQHZ      	200
#define VARIO_SPKR_MAX_FREQHZ       3200

// three octaves (2:1) of frequency for climbrates below crossoverCps,
// and one octave of frequency for climbrates above crossoverCps.
// This gives you more perceived frequency discrimination for climbrates 
// below crossoverCps
#define VARIO_CROSSOVER_FREQHZ    	1600

#define KF_ADAPT         1.0f

// Acceleration bias uncertainty is set low as the residual acceleration bias 
// (post-calibration) is expected to have low variation/drift. It is further reduced
// depending on the acceleration magnitude, as we want the acceleration bias estimate 
// to evolve ideally in a zero acceleration environment.
#define KF_ACCELBIAS_VARIANCE   	0.005f

// KF4 Acceleration Measurement Noise variance
#define KF_A_MEAS_VARIANCE   		10.0f

// KF4 Altitude Measurement Noise Variance
#define KF_Z_MEAS_VARIANCE			200.0f

// If climbrate or sinkrate stays below this threshold for the configured
// time interval, vario goes to sleep to conserve power
#define PWR_OFF_THRESHOLD_CPS    	50

// if you find that gyro calibration fails even when you leave
// the unit undisturbed, increase this offset limit
// until you find that gyro calibration works consistently.
#define GYRO_OFFSET_LIMIT_1000DPS   200
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

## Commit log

2022-01-26 reduce tx power
2022-03-11 SPI interface, Kicad schematic and layout
    [espc3-vario-B_Cu.gbl, espc3-vario-B_Mask.gbs, espc3-vario-B_Paste.gbp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]
2022-03-11 update schematic pdf
2022-03-11 remove kicad subdirectory
    [espc3-vario-B_Cu.gbl, espc3-vario-B_Mask.gbs, espc3-vario-B_Paste.gbp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]
2022-05-07 calib adc, modify kf4, bt led 1hz
2022-05-12 webpage button resize
2022-05-13 use esp32-c3-devkitm-1 env
2022-05-15 revert to kf adapt as user param
    [config.h, main.cpp]
2022-05-15 power off tone changed
2022-08-09 power off delay, revA/B
2022-08-14 fix hw rev b
    [config.h, main.cpp]
2022-08-14 mod partitions
    [partitions.csv]
2022-09-12 change ble tx power
2025-04-05 fix compile errors for latest libraries
    [audio.cpp, config.h, main.cpp]
2025-04-07 change ledc* api to be compatible with arduino 2.x used by platformio
2025-04-24 only support pcb layout rev B
    [no_ota_2mb.csv]
